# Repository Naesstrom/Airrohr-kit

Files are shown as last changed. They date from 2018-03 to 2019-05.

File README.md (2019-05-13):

# Airrohr Kit
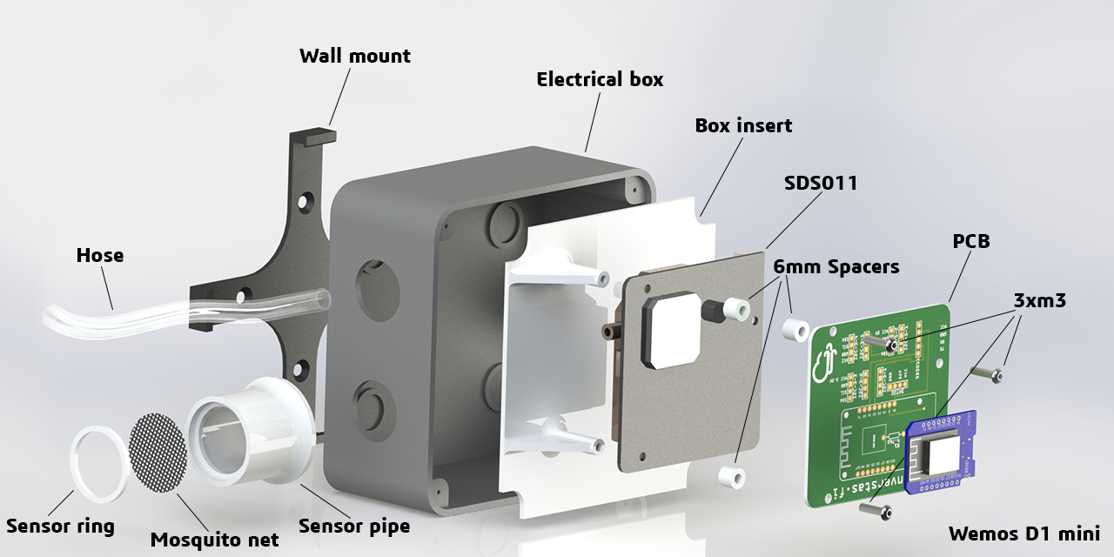
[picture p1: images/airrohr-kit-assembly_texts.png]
<br>

Table of Contents
=================

   * [Introduktion](#introduktion)
   * [Airrohr-PCB](#airrohr-pcb)
      * [versions](#versions)
         * [Airrohr Wemos](#airrohr-wemos)
         * [Airrohr NodeMCU](#airrohr-nodemcu)
         * [luftdata.se Wemos](#luftdatase-wemos)
         * [luftdata.se NodeMCU](#luftdatase-nodemcu)
      * [Custom versions](#custom-versions)
         * [vekotinverstas.fi](#vekotinverstasfi)
   * [BOM (Bill Of Materials)](#bom-bill-of-materials)
      * [Hardware](#hardware)
      * [3D printed parts](#3d-printed-parts)
      * [For the PCB](#for-the-pcb)
   * [Assembly <em>(work in progress for the new parts)</em>](#assembly-work-in-progress-for-the-new-parts)

Created by [gh-md-toc](https://github.com/ekalinin/github-markdown-toc)

## Introduktion
I got involved in the Airrohr (Luftdaten, Luftdata.se) project in 2017 and it hadn't gained all that momentum yet so most parts was _(and still are)_ connected just with some dupont wires and stuffed into a pipe on the wall! It works but maybe not that pretty and to make it more stable something more sturdy then cables might be used.

Since I'm no programmer but wanted to contribute to the project in some way I started making 3D parts like a [stevensson screen](https://www.thingiverse.com/thing:2821592) for the sensor bit that to felt a bit bulky so this is a more streamlined version.

My goal with this project is to create a easy to use kit that can be made or ordered and requires minimal soldering skills and still looks good. For information about flashing firmware etc. please see [Luftdaten.info](http://luftdaten.info)

Now you have to choose a path, either you go all in and buy the electrical box, print all the parts for the complete kit or you just order the PCB and insert it into a standard pipe as the original.

This is how the finished assembly can look with the board showing. Imagine a lid on the box and another bend in the pipe!

| Electrical Box | Pipe |  
| --- | --- |
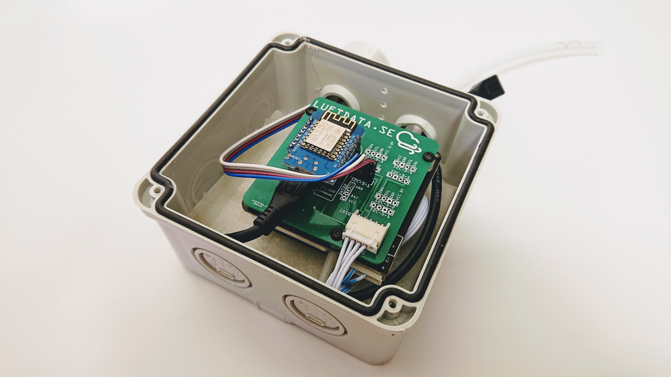
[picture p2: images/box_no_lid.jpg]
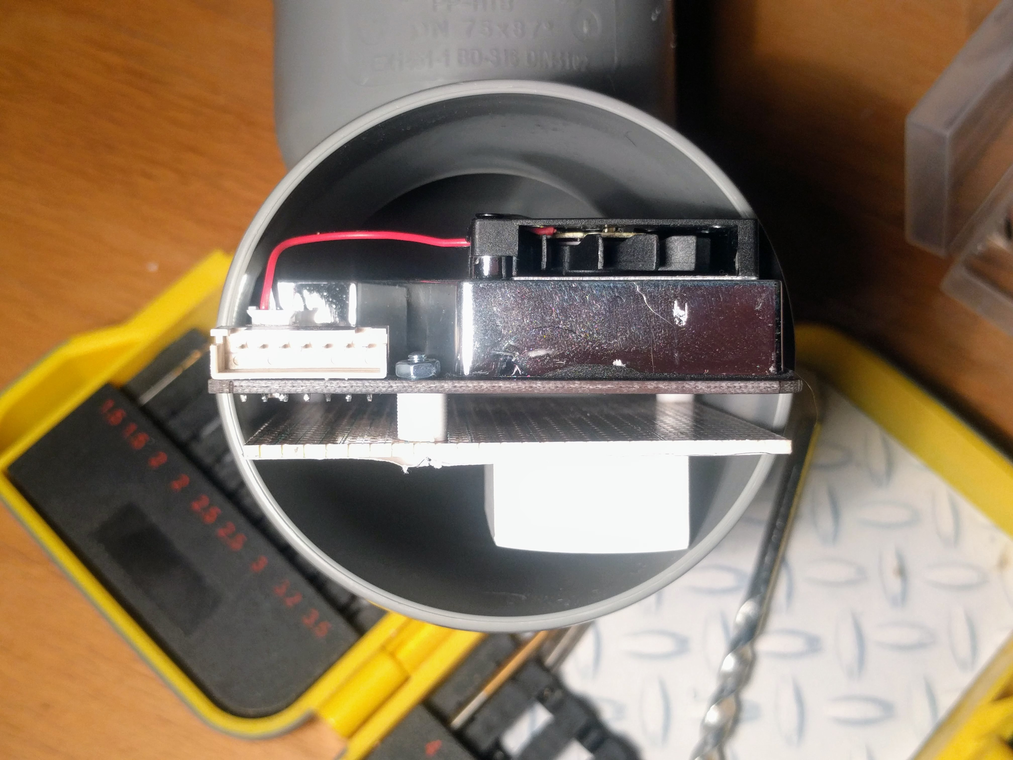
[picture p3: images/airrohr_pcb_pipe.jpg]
|  |  |

## Airrohr-PCB
So this is the main part, the _pièce de résistance_ as one might call it of this entire project! Solder on some header pins and insert the ESP8266 of your choice, connect the standard cables that comes with the SDS011 to the connector and you're ready!
The PCB also features:
 - 5 different I2C connectors at 3.3V for sensors
 - 2 different I2C connectors at 5V for LED, OLED etc.
 - 1 connection for [Adafruit ADS1115 16-Bit ADC](https://www.adafruit.com/product/1085) for DB meters and other analog sensors.

### versions
There are a couple different versions each in their own folder with Gerber files:<br>
*(Fritzing version is also available)*
#### Airrohr Wemos
This is labeled with the airrohr project name and good for general use.<br>
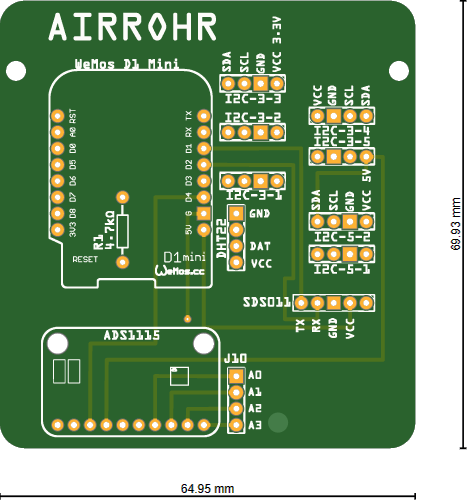
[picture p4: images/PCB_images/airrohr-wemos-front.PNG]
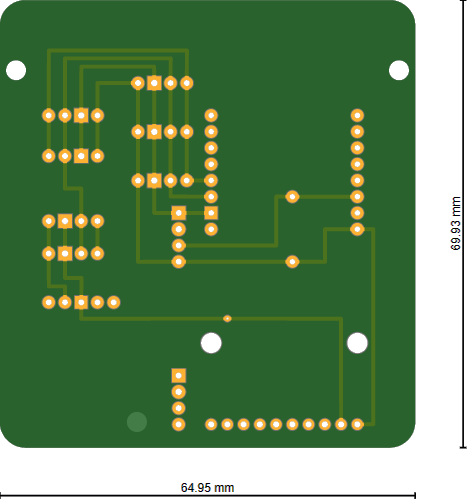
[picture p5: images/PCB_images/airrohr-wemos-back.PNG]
<br>
Order at [Aisler](https://aisler.net/p/MCOILVZU)

#### Airrohr NodeMCU
This is made to fit either a NodeMCU v1, v2 or even the Lolin v3 that has a bigger footprint.<br>
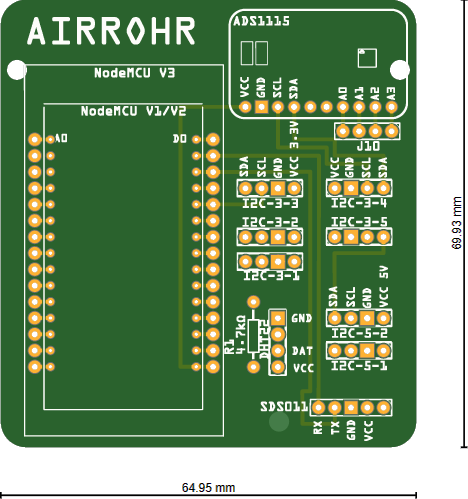
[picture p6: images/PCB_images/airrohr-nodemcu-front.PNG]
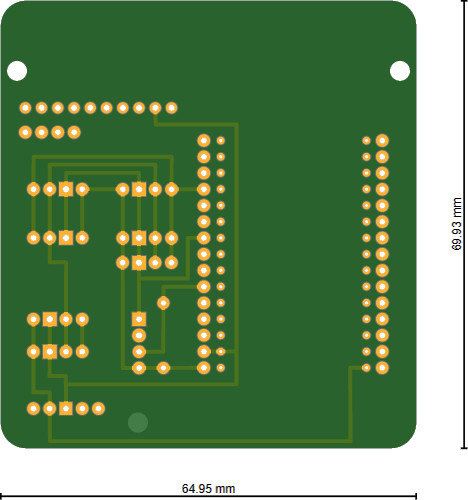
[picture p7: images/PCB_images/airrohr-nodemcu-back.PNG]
<br>
Order at [Aisler](https://aisler.net/p/XHFMJADZ)

#### luftdata.se Wemos
This is labeled for the Swedish version of the project at [luftdata.se](http://www.luftdata.se) but other then that it's the same layout as the airrohr version above. <br>
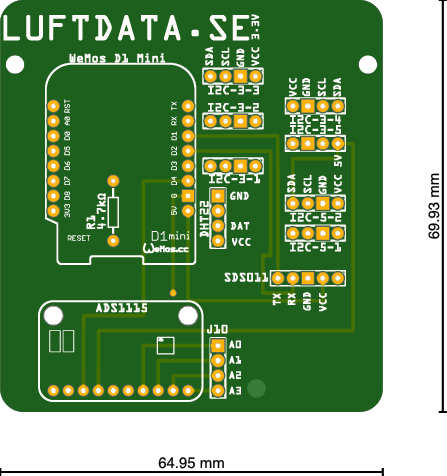
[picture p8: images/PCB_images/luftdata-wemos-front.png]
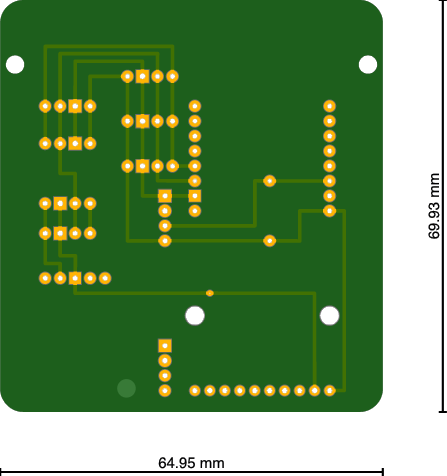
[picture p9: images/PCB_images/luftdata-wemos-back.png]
<br>
Order at [Aisler](https://aisler.net/p/RLNYRZNS)

#### luftdata.se NodeMCU
This is labeled for the Swedish version of the project at [luftdata.se](http://www.luftdata.se) but other then that it's the same layout as the airrohr version above. <br>
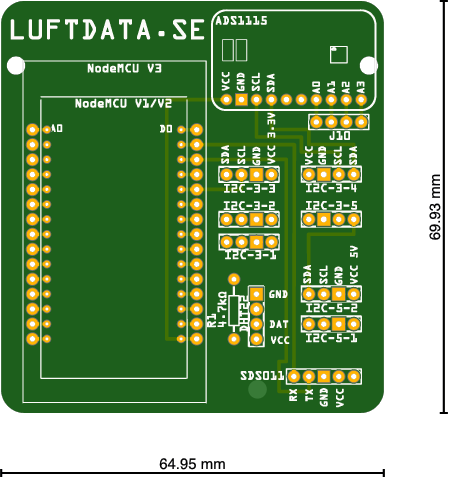
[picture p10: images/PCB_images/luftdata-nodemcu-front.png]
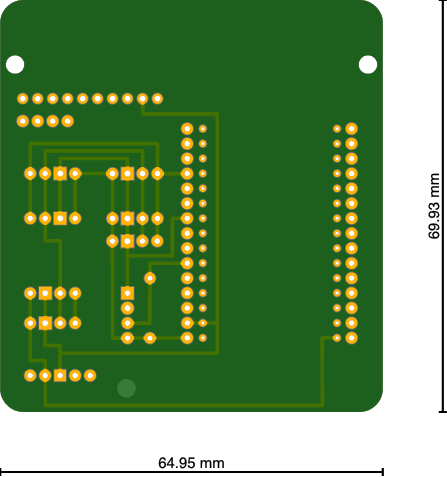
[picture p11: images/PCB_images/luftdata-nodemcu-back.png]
<br>
Order at [Aisler](https://aisler.net/p/VWREQBIH)

### Custom versions

#### [vekotinverstas.fi](http://vekotinverstas.fi/)
This is a custom board I made for the Finnish iniative [vekotinverstas.fi](http://vekotinverstas.fi/) who uses the Wemos Mini Pro v2 instead and LoRaWan to be able to spread the sensors out in entire cities. Really impressive work so head over to their homepage and check it out _(google translate works well enough)_

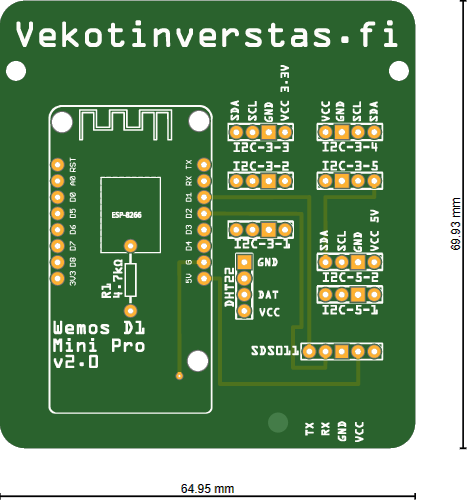
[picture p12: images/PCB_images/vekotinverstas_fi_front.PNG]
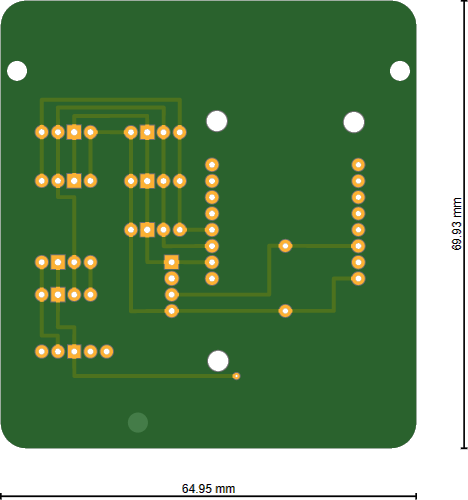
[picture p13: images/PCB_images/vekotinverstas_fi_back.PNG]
<br>
Order at [Aisler](https://aisler.net/p/LDIEGBRF)

## BOM (Bill Of Materials)

### Hardware
 - SDS011 Particle sensor
 - ESP8266 (NodeMCU or Wemos D1 mini/pro)
 - Sensor (DHT22, BME280, BMP280 etc)
 - Electrical Box _(3D parts are custom for Biltema 46-2021, 116x116x76mm)_
 - Hose 6mm Inner diameter, 200mm long
 - 3x M3x12 screws
 - 1-4 Wood screws to attach to wall

### 3D printed parts
 - 3x 6mm spacer
 - 1x Airrohr stencil _(optional for painting)_
 - 1x Luftdata stencil _(optional for painting)_
 - 1x Airrohr wall mount
 - 1x Airrohr box sensor pipe _(For 28mm grommets)_
 - 1x Airrohr box sensor ring
 - 1x Airrohr box insert

### For the PCB
 - 2x 1x8 pin header for the wemos _(alternatively 1x15 for the NodeMCU)_
 - 1x4 pin header _(as many as the number of I2C components you want to add)_
 - 1x4 pin header for the DHT22
 - 1x 4.7kOhm resistor for the DHT22
 - 1x JST-XH 5-pin angled connector (800624)
 - 3x 6mm nylon spacers with nuts/screws or 3d printed alternative.

## Assembly _(work in progress for the new parts)_
So this is where you make your choice, a rather small one so don't procrastinate about it since you can always switch between the models. The most important decision is that you want to be a part of the project and help measuring air quality!

Your choices are simply either to build the simpler option with pipes or the tad more advanced version with electrical box and 3d printed parts. You can always start with the pipe version and upgrade later! There's even a version without a PCB that you can find over at [luftdaten.info](http://luftdaten.info) _(international)_ or [luftdata.se](http://luftdata.se) _(Swedish)_ but you still require some hardware like the particle sensor and ESP.

#### 1. solder on headers
Solder on all the headers/sockets that you want to use for your project<br>
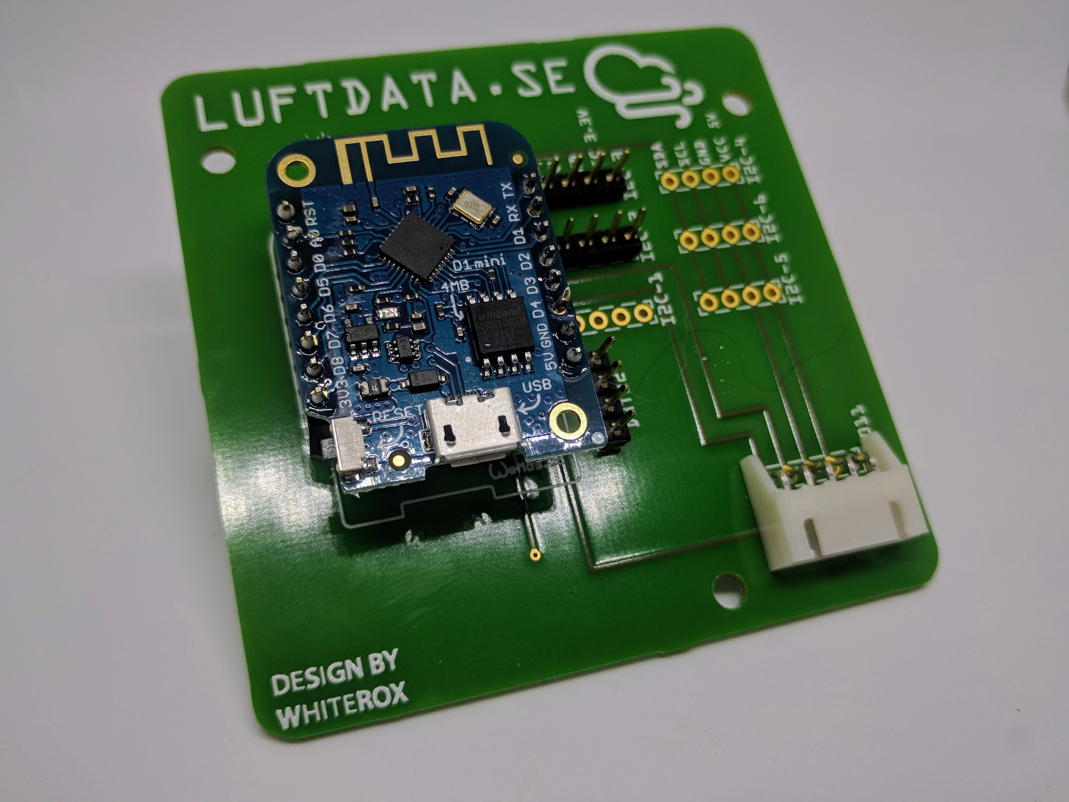
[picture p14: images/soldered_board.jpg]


### Make your choice
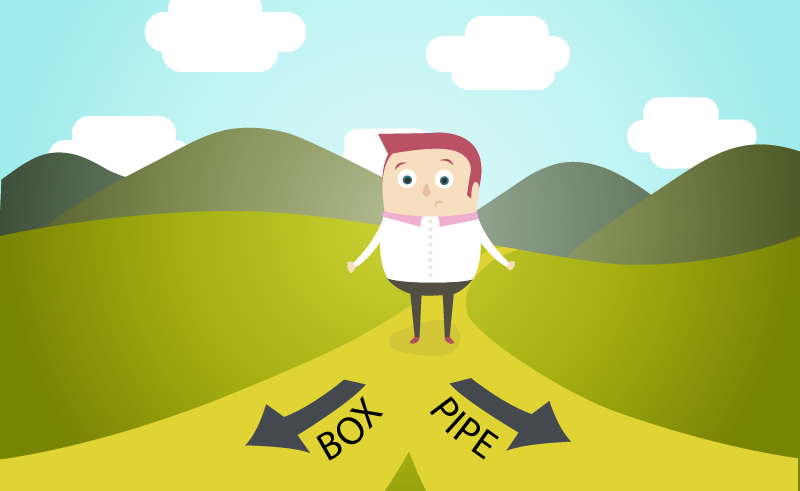
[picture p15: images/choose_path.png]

Keep reading to make a Pipe version or click here to [continue to B1](#b1---insert-bottom-plate-into-box) to make a box version

#### P1 - Attach the PCB
Use the nylon spacers and screws/nuts to mount the board to the bottom of the SDS011 sensor and then connect the cable between the sensor and the board:<br>
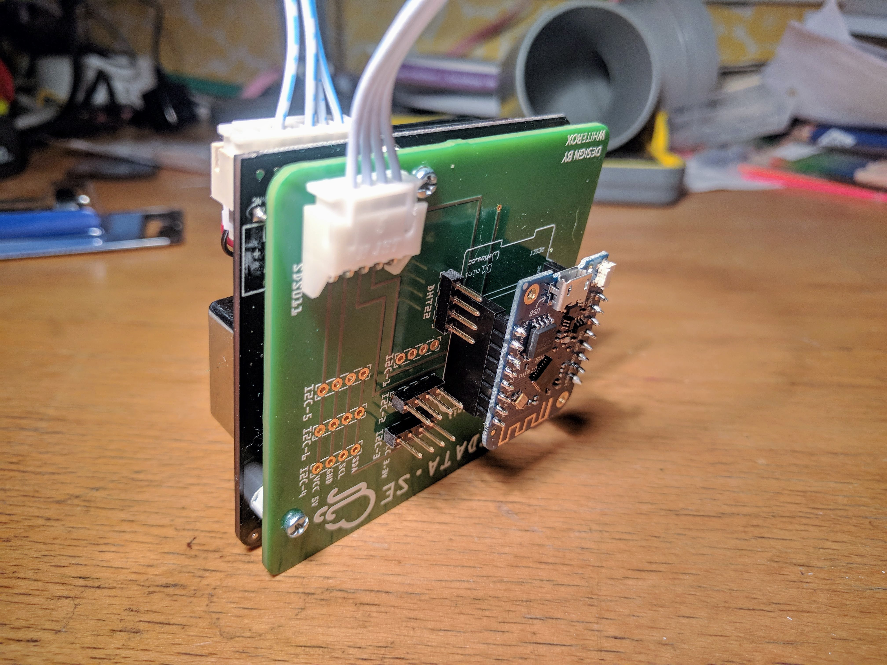
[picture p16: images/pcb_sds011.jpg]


#### P2 - Insert into pipe
The complete package is designed to fit into the 75mm sewer pipe system that the airrohr project uses for mounting and securing the sensor:<br>
<br>
_(dummy wemos on the image)_

### B1 - Insert bottom plate into box

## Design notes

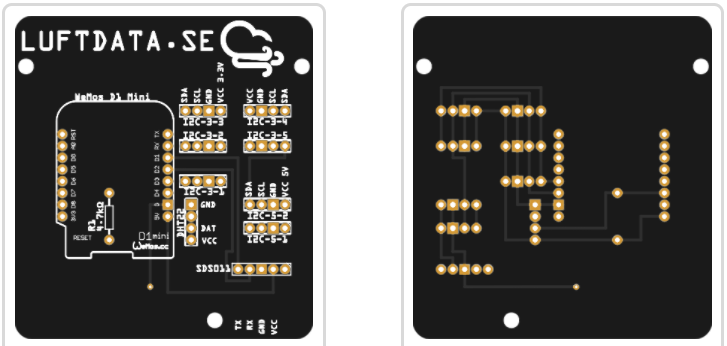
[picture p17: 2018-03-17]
images/luftdata_screen.png

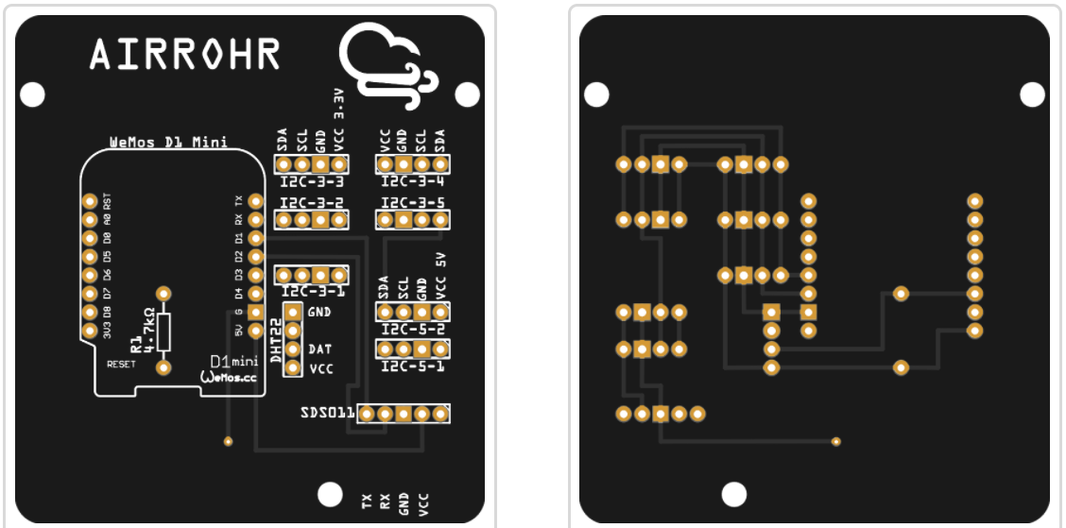
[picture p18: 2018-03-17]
images/airrohr_screen.png

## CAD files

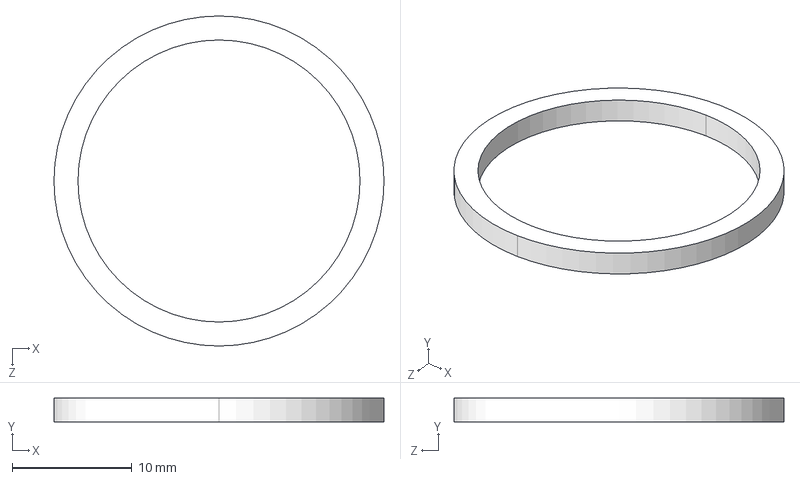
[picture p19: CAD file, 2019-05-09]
3D-files/STEP/Airrohr_box_sensor_ring.STEP
27.5 x 2.00 x 27.5 mm

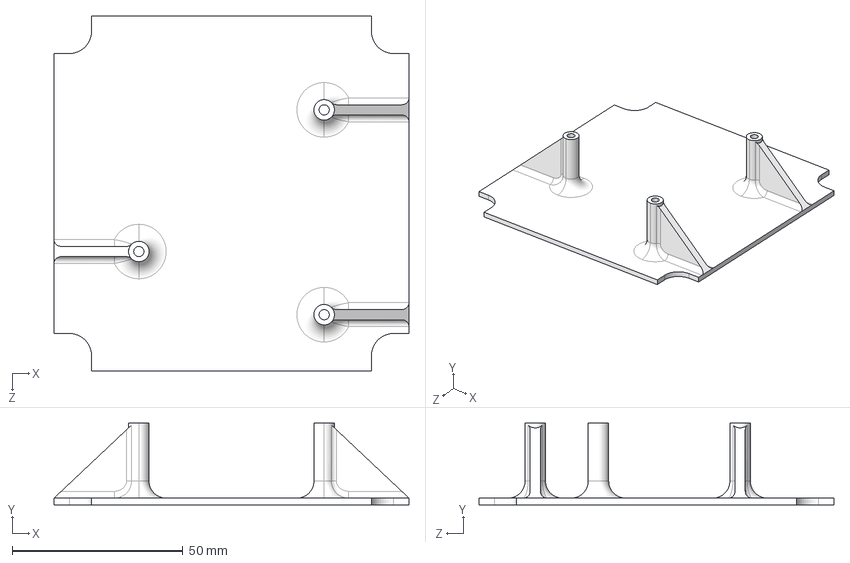
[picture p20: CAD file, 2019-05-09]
3D-files/STEP/airrohr_box_insert.STEP
104.0 x 24.0 x 104.0 mm

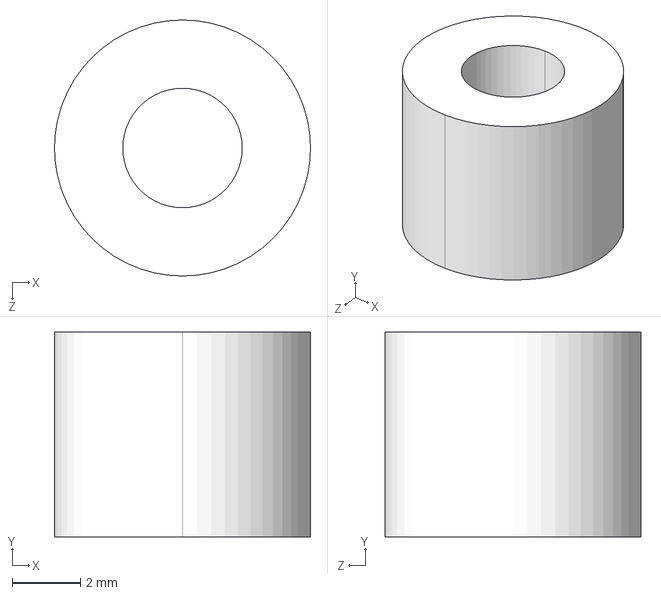
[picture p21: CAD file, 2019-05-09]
3D-files/STEP/6mm_spacer.STEP
7.50 x 6.00 x 7.50 mm

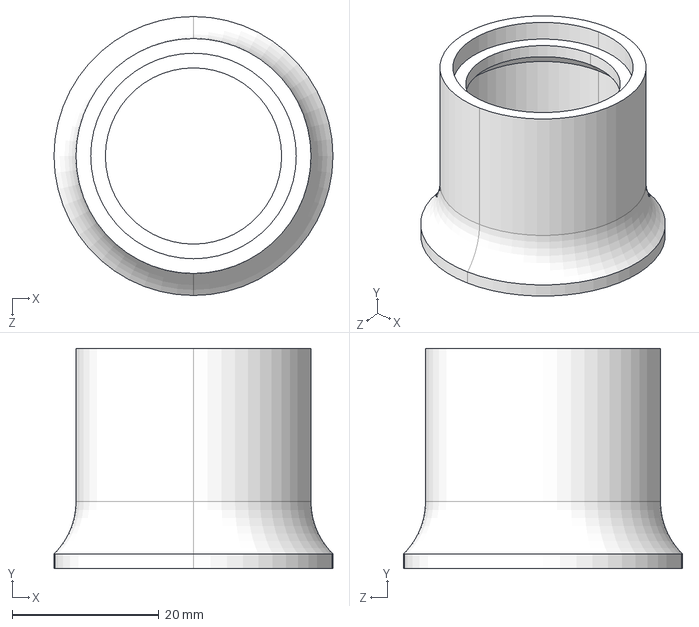
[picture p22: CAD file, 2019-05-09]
3D-files/STEP/Airrohr_box_sensor_pipe.STEP
38.0 x 30.0 x 38.0 mm

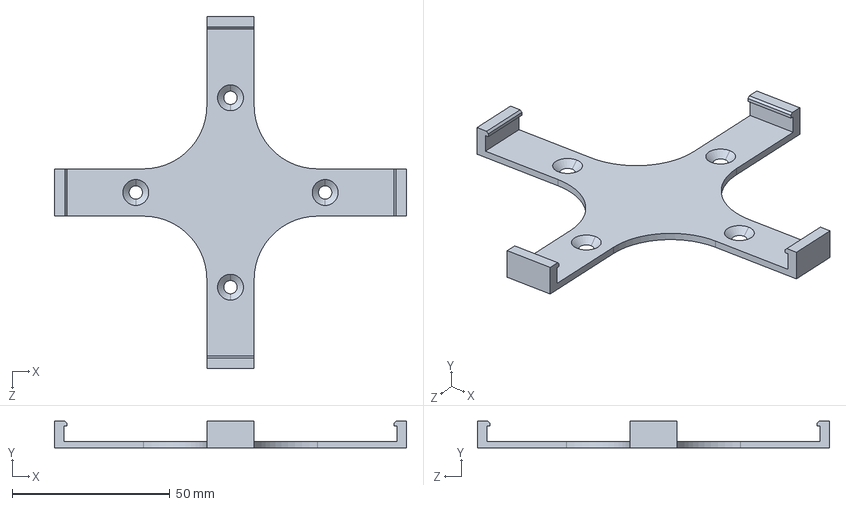
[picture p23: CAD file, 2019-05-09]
3D-files/STEP/Airrohr-wall-mount.STEP
111.5 x 8.45 x 111.5 mm

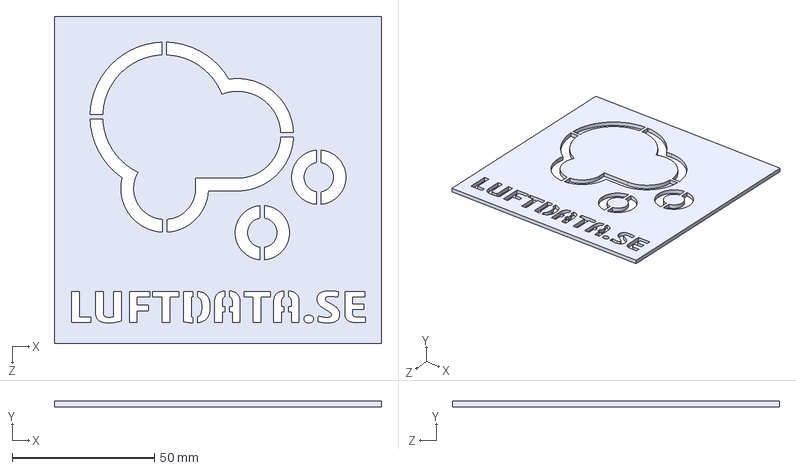
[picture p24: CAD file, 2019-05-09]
3D-files/STEP/Luftdata-stencil.STEP
115.0 x 2.00 x 115.0 mm

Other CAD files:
3D-files/STEP/Airrohr-stencil.STEP
3D-files/STL/6mm_spacer.STL
3D-files/STL/Airrohr-stencil.STL
3D-files/STL/Airrohr-wall-mount.STL
3D-files/STL/Airrohr_box_sensor_pipe.STL
3D-files/STL/Airrohr_box_sensor_ring.STL
3D-files/STL/Luftdata-stencil.STL
3D-files/STL/airrohr_box_insert.STL
3D-files/Solidworks/6mm_spacer.SLDPRT
3D-files/Solidworks/Airrohr-stencil.SLDPRT
3D-files/Solidworks/Airrohr-wall-mount.SLDPRT
3D-files/Solidworks/Airrohr_box_sensor_pipe.SLDPRT
3D-files/Solidworks/Airrohr_box_sensor_ring.SLDPRT
3D-files/Solidworks/Luftdata-stencil.SLDPRT
3D-files/Solidworks/airrohr_box_insert.SLDPRT

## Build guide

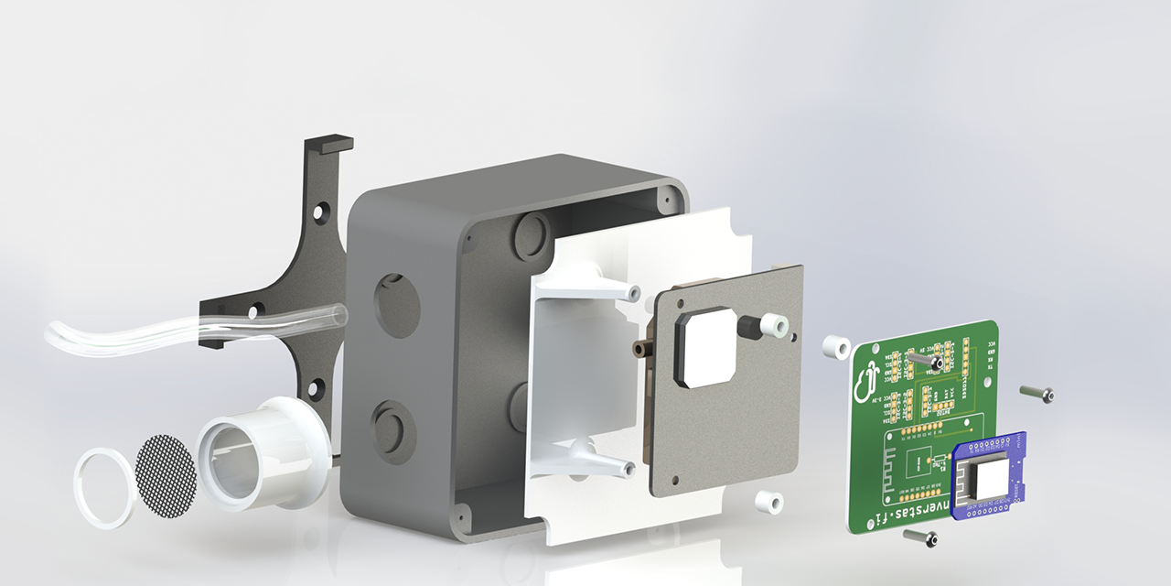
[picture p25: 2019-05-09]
images/airrohr-kit-assembly.png

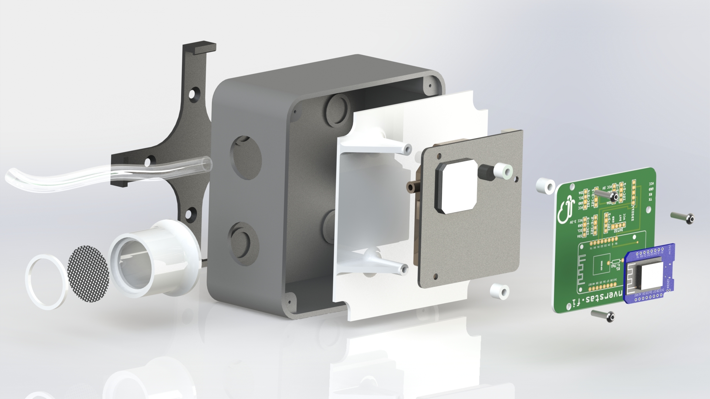
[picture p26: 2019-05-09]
images/airrohr-kit-assembly.JPG

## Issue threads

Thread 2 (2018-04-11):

DHT22 female header or direct solder?

Cinezaster, 2018-04-11:
How do you connect the DHT22 to the board?
I see in the photo that it has male headers soldered to it.

Wouldn't it be a beter idea to put the DHT22 directly on the board, next to the SDS011 connector or opposite side in the area of the SDS011 input?
Experience learned that the wired connection between DHT22 sensor is a weak point because of the thin leads of the DHT22 sensor.
Having it to close to the NodeMcu or WeMos is also a problem because it radiates extra heat and can influence the data.

For our [LoraWan version](https://twitter.com/DVRansbeeck/status/951022161589829632) we put the DHT22 underneath the NodeMcu. Not our best idea ;-)
In June we're going to deploy an extra 100 sensors in Brussel (influencair.be), It would be cool to have a pcb like this.

ricki-z, 2018-10-20:
The temperature sensors should be places 'near' the ambient air. Beside the NodeMCU and the SDS011 you may get values some degrees too high.

Naesstrom, 2018-11-20:
My god I've been a bad creator not replying!

Yeah I soldered some male headers and attached them with normal jumper cables, making sure to use some zip ties to fasten it as good as I could.
I guess one way would be to get some JST XH 2.5mm 4-Pin Connectors like [these](https://www.ebay.com/itm/20Sets-JST-2-54mm-4-Pin-Battery-Connector-Plug-Female-Male-with-Wire-/112644765822) to get a more secure connection.
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

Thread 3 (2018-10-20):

Wish: including A/D converter

ricki-z, 2018-10-20:
@Naesstrom : Do you think it's possible to include a place for an ADS1115 and 4 pins for analogue input? We are working on an acoustic sensor and a NO2 sensor that both have analogue output.

Rajko from Luftdaten.info

Naesstrom, 2018-11-20:
First of all I'm sorry for the late reply!
I'll see, shouldn't be impossible :D

Naesstrom, 2018-11-20:
@ricki-z something like this?
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

Naesstrom, 2018-11-20:
I just kept going and managed to add one to the NodeMCU version to
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

ricki-z, 2018-11-21:
@Naesstrom Thank you. We were working on a noise sensor, for which we are using the A/D converter. But this that extra piece of hardware a pcb is much better than our floating wiring.

Naesstrom, 2019-05-10:
ADS1115 is now added to all versions of the PCB

Closed 2019-05-10.

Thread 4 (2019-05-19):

Difference between NodeMCU V1,V2 and V3

ricki-z, 2019-05-19:
The difference between NodeMCU V1 (or V2) and V3 is the 5V pin.
For V1/V2 you need to use VIN left of the USB connector.
But for V3 you can't use this pin as there is a diode that is blocking the 5V coming from the USB. Here you need to use the pin VU left of the esp8266 chip.
This should be changed on the NodeMCU boards. But I think this could be solved with a jumper.

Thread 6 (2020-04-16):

Lost but found!

Bergerie, 2020-04-16:
I’m thrilled I found this hidden treasure. Like so many of us in Europe, I have taken this DIY project on board with a lot of pleasure. In order to put an appropriate assembly package together, I was contemplating getting something done with Fritzing with a steep learning curve. To my delight, I hit your site with outstanding info and support for my endeavor. If I bump into problems, I hope I could consult you whilst customizing the board.
Rgds
Dick

Naesstrom, 2020-04-17:
Hi and I'll do my best to help if needed ofcourse!

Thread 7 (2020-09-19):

M10CUBE thanks you

M10CUBE, 2020-09-19:
I found myself here looking for an SDS011  footprint. Excellent work done here. On top of that please we can join forces if you like We are building a similar project called M10CUBE and part of it is our sensor PCB. Everything is connected to a RASPI 40 pin connector for modularity and expand-ability without limits. I think that can be a step forward on the job done so far.
We are working the project on slack. I you want to contribute there and make it better please tell me so to invite you.
Meanwhile I will use your material here to help me out on SD011 encapsulation.
You can find our project here:
https://hackaday.io/project/171770/files
And here:
https://gitlab.com/m10cube/m10
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

All final m10-sensor design files (KiCAD and 3D) will be uploaded on GitLAB as soon as possible
Thank you for the hospitality. I hope we can do more together

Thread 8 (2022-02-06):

SDS011 and BME280 on Wemos

JVaassen, 2022-02-06:
I am trying to build this, but I run into a conflict (I assume) :
D1/D2 on Wemos D1 Mini are SDA/SCL lines for the I2C bus.
According to the schematics, the SDS011 is also connected by default to D1/D2 on a Wemos running a serial Protocol.

SDS is running on 5V, BME280 is running at 3.3V, on the same pins ?

How can this work ?

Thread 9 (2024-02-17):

Aisler: can't import project

Arthur-Philip-Dent, 2024-02-17:
Hi Naesstrom!
Thanks for rocking this! I just had an issue importing the PCB At AISLER: PCB outline missing (when clicking "import" at the AISLER account).

How can I solve that?
Thanks for reply!

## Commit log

2018-03-16 pipe pcb image
2018-03-16 added fritzing
    [luftdata_pcb_wemos.fzz]
2018-03-16 Fixed some gerber files
    changed type on the contour files and removed pnp files
2018-03-17 Uppdated wires
    Changed order of the RX/TX on sds011 connector to match the cable
    [luftdata_pcb_wemos.fzz]
2018-03-17 Saved new gerbers
    [airrohr_pcb_wemos.fzz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]
2018-03-19 Testing a bare ESP layout
    [luftdata_pcb_ESP12.fzz]
2018-04-06 Added NodeMCU
    [luftdata_pcb_NodeMCU.fzz]
2018-04-06 Added MCU gerber
2018-04-06 Added NodeMCU V1
    [luftdata_pcb_NodeMCU_V1.fzz, luftdata_pcb_NodeMCU_V3.fzz]
2018-04-06 Added Gerbers
    [luftdata_pcb_NodeMCU_V3.fzz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]
2018-11-20 Merge and added ADS1115
    Merged the two NodeMCU versions as one since the V2/V1 fits inside the footprint of V3.
    Added ADS1115 to both models by request.
    [airrohr_pcb_wemos.fzz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]
2018-11-20 Updated Wemos
    [airrohr_pcb_wemos.fzz]
2019-04-27 Added custom version
    [Vekotinverstas_pcb_wemos.fzz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]
2019-04-27 Added multi version with ADS1115
    [airroht_pcb_NodeMCU_V1_V2_V3_ADS1115.fzz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]
2019-05-09 Change layout
    [Airrohr_pcb_NodeMCU_V1_V2_V3_ADS1115.fzz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]
2019-05-09 Added new gerbers
    [Airrohr_pcb_wemos.fzz, Airrohr_pcb_wemos_d1_mini_pro_ADS1115.fzz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]
2019-05-09 Added 3D-files
    [6mm_spacer.SLDPRT, 6mm_spacer.STEP, 6mm_spacer.STL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]
2019-06-01 changed pin for 5V for NodeMCU V3
    [Airrohr_pcb_NodeMCU_V1_V2_V3_ADS1115.fzz, Luftdata_pcb_NodeMCU_V1_V2_V3_ADS1115.fzz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]
